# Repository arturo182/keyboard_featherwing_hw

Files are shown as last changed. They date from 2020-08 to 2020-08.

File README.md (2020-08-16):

# The Keyboard FeatherWing

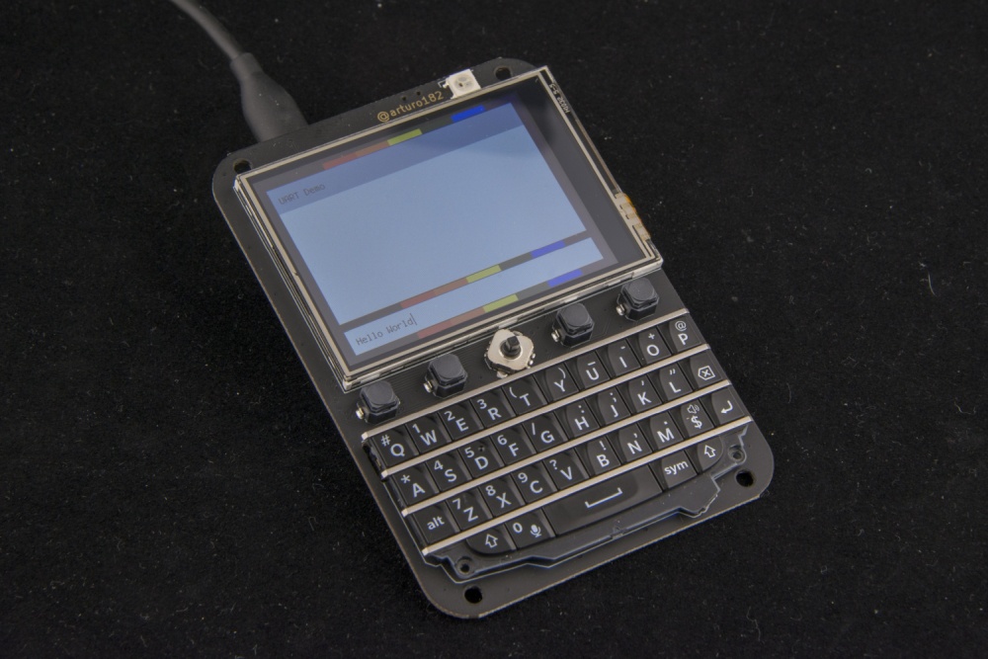
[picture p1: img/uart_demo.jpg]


The Keyboard FeatherWing is an easy way to add a handheld Qwerty keyboard and a 2.6” color display (+ more) to your project! It fits well in your hands and is great for typing with your thumbs, early 2000s-style.

The FeatherWing itself does not contain an MCU/CPU/SoC that you can program; you will need a board compatible with the [Adafruit Feather System](https://learn.adafruit.com/adafruit-feather/feather-specification).

# Technical details
- 2.6” 320x240 16-bit color LCD with resistive touch screen
- QWERTY keyboard
- 5-way button
- 4 soft tactile buttons
- A Neopixel
- microSD connector
- Stemma QT/Qwiic connector
- On/Off switch
- Dual row sockets
- Four mounting holes
- GPIO solder jumpers

# Links

For more information visit https://kfw.solder.party/

You can find example code here: https://github.com/arturo182/keyboard_featherwing_sw

This board uses a ATSAMD20 chip as a i2c peripheral that can be polled to get the key FIFO, the firmware for the SAM can be found here: https://github.com/arturo182/bbq10kbd_i2c_sw

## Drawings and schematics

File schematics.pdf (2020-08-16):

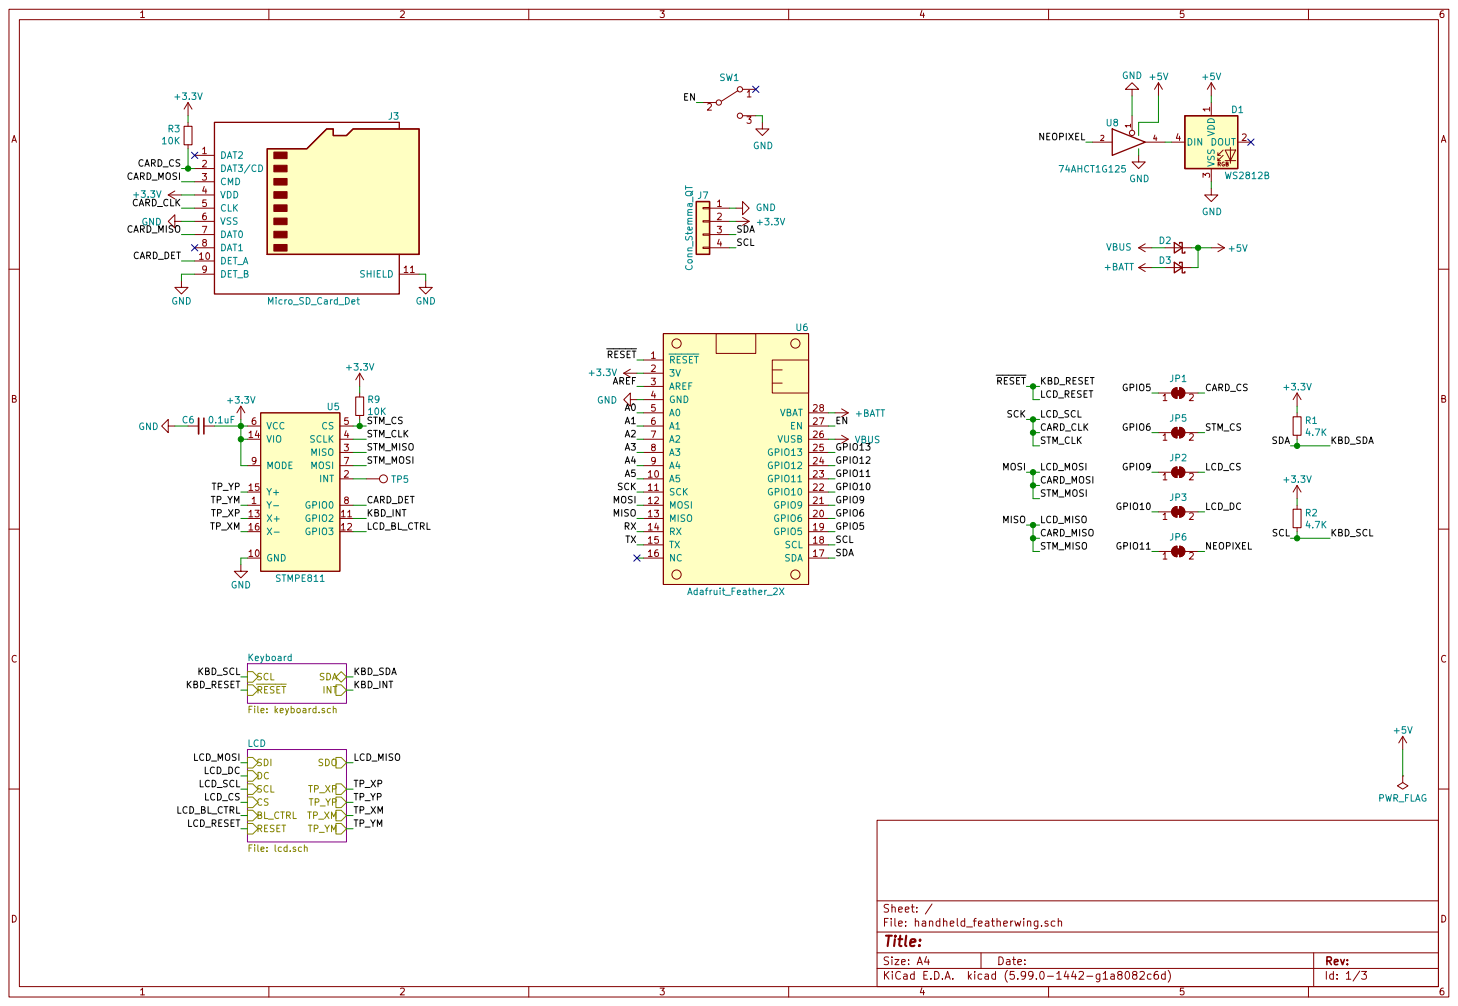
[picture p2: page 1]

File: handheld_featherwing.sch Sheet: / Keyboard

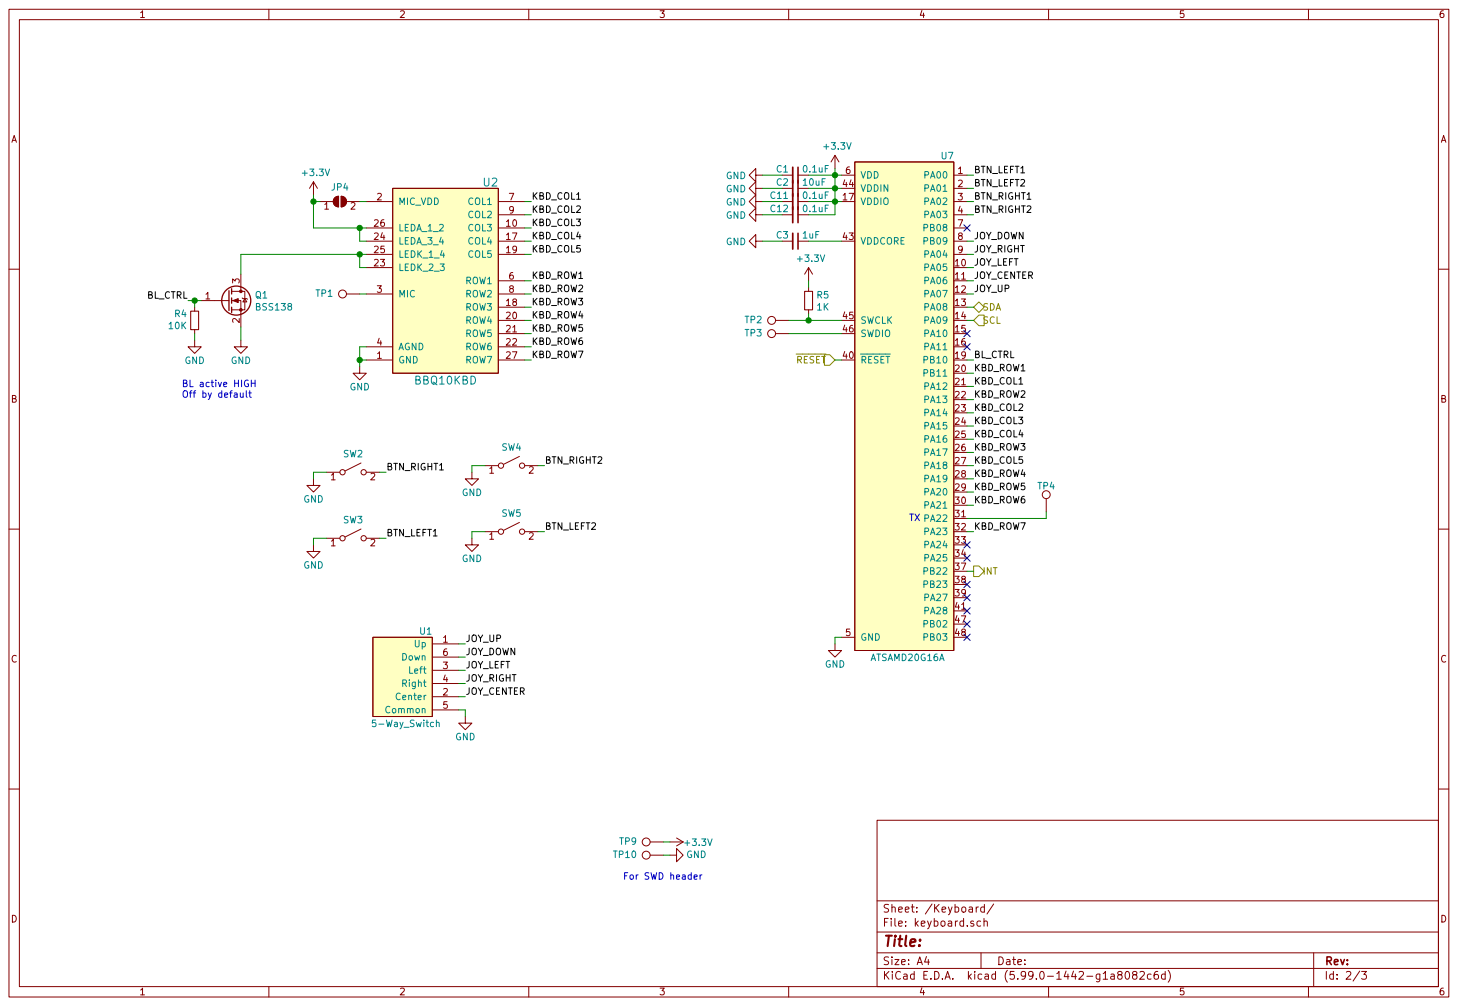
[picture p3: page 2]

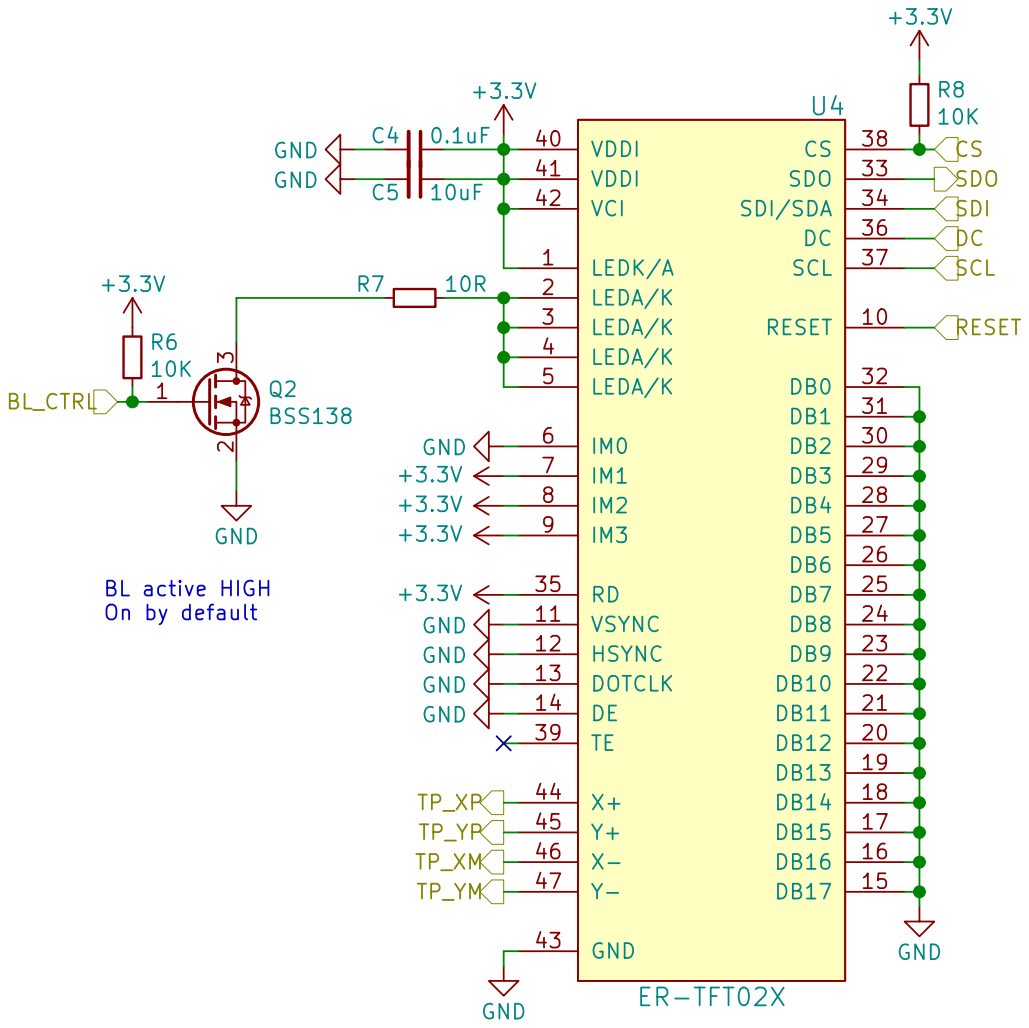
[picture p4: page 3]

Id: 3/3 Title: File: lcd.sch Sheet: /LCD/ GND GND

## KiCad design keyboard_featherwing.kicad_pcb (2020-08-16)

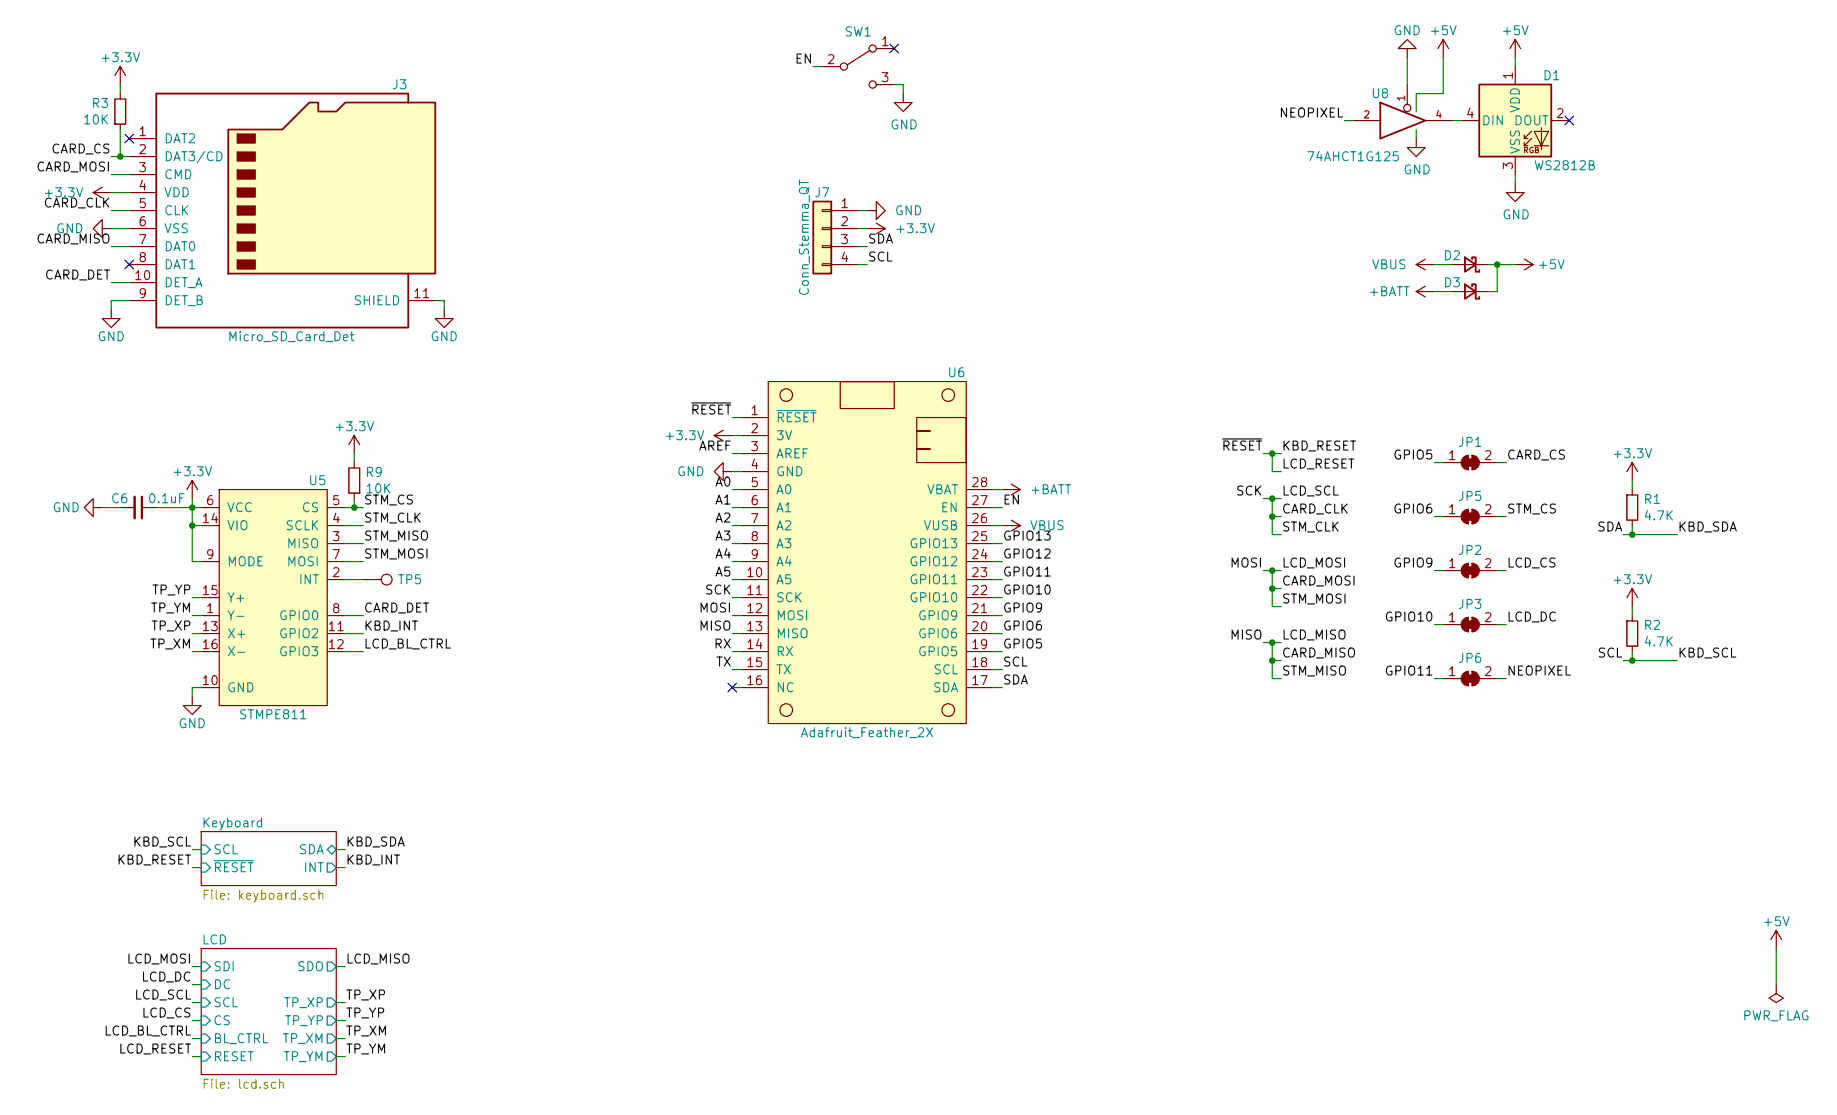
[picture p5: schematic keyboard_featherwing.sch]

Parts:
C6: 0.1uF; C_0603_1608Metric
D1: WS2812B; LED_WS2812B_PLCC4_5.0x5.0mm_P3.2mm
D2, D3: S1JHE; D_SOD-323_HandSoldering
J3: Micro_SD_Card_Det; microSD_HC_Molex_104031-0811
J7: Conn_Stemma_QT; JST_SH_SM04B-SRSS-TB_1x04-1MP_P1.00mm_Horizontal
JP1: SB_CARD_CS; SolderJumper-2_P1.3mm_Bridged_RoundedPad1.0x1.5mm
JP2: SB_LCD_CS; SolderJumper-2_P1.3mm_Bridged_RoundedPad1.0x1.5mm
JP3: SB_LCD_DC; SolderJumper-2_P1.3mm_Bridged_RoundedPad1.0x1.5mm
JP5: SB_STM_CS; SolderJumper-2_P1.3mm_Bridged_RoundedPad1.0x1.5mm
JP6: SB_NEOPIXEL; SolderJumper-2_P1.3mm_Bridged_RoundedPad1.0x1.5mm
R1, R2: 4.7K; R_0603_1608Metric
R3, R9: 10K; R_0603_1608Metric
SW1: SW_EN; SW_SPDT_PCM12
TP5: TP_STM_INT; TestPoint_Pad_D3.0mm
U5: STMPE811; QFN-16-1EP_3x3mm_P0.5mm_EP1.75x1.75mm
U6: Adafruit_Feather_2X; FeatherWing
U8: 74AHCT1G125; SOT-353_SC-70-5

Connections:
+3V3: C6.1, J3.4 (VDD), J7.2, R1.1, R2.1, R3.2, R9.2, U5.6 (VCC), U5.9 (MODE), U5.14 (VIO), U6.2 (3V); also elsewhere on the board
+5V: D1.1 (VDD), D2.1 (K), D3.1 (K), U8.5 (VCC)
+BATT: D3.2 (A), U6.28 (VBAT)
/A0: U6.5 (A0)
/A1: U6.6 (A1)
/A2: U6.7 (A2)
/A3: U6.8 (A3)
/A4: U6.9 (A4)
/A5: U6.10 (A5)
/AREF: U6.3 (AREF)
/CARD_CLK: J3.5 (CLK), U5.4 (SCLK), U6.11 (SCK); also elsewhere on the board
/CARD_CS: J3.2 (DAT3/CD), JP1.2 (B), R3.1
/CARD_DET: J3.10 (DET_A), U5.8 (GPIO0)
/CARD_MISO: J3.7 (DAT0), U5.3 (MISO), U6.13 (MISO); also elsewhere on the board
/CARD_MOSI: J3.3 (CMD), U5.7 (MOSI), U6.12 (MOSI); also elsewhere on the board
/EN: SW1.2 (B), U6.27 (EN)
/GPIO5: JP1.1 (A), U6.19 (GPIO5)
/GPIO6: JP5.1 (A), U6.20 (GPIO6)
/GPIO9: JP2.1 (A), U6.21 (GPIO9)
/GPIO10: JP3.1 (A), U6.22 (GPIO10)
/GPIO11: JP6.1 (A), U6.23 (GPIO11)
/GPIO12: U6.24 (GPIO12)
/GPIO13: U6.25 (GPIO13)
/KBD_INT: U5.11 (GPIO2); also elsewhere on the board
/KBD_RESET: U6.1 (~RESET~); also elsewhere on the board
/KBD_SCL: J7.4, R2.2, U6.18 (SCL); also elsewhere on the board
/KBD_SDA: J7.3, R1.2, U6.17 (SDA); also elsewhere on the board
/LCD_BL_CTRL: U5.12 (GPIO3); also elsewhere on the board
/LCD_CS: JP2.2 (B); also elsewhere on the board
/LCD_DC: JP3.2 (B); also elsewhere on the board
/NEOPIXEL: JP6.2 (B), U8.2
/RX: U6.14 (RX)
/STM_CS: JP5.2 (B), R9.1, U5.5 (CS)
/TP_XM: U5.16 (X-); also elsewhere on the board
/TP_XP: U5.13 (X+); also elsewhere on the board
/TP_YM: U5.1 (Y-); also elsewhere on the board
/TP_YP: U5.15 (Y+); also elsewhere on the board
/TX: U6.15 (TX)
GND: C6.2, D1.3 (VSS), J3.6 (VSS), J3.9 (DET_B), J3.11 (SHIELD), J7.1, SW1.3 (C), U5.10 (GND), U6.4 (GND), U8.1, U8.3 (GND); also elsewhere on the board
unnamed: D1.4 (DIN), U8.4
unnamed: TP5.1, U5.2 (INT)
VBUS: D2.2 (A), U6.26 (VUSB)

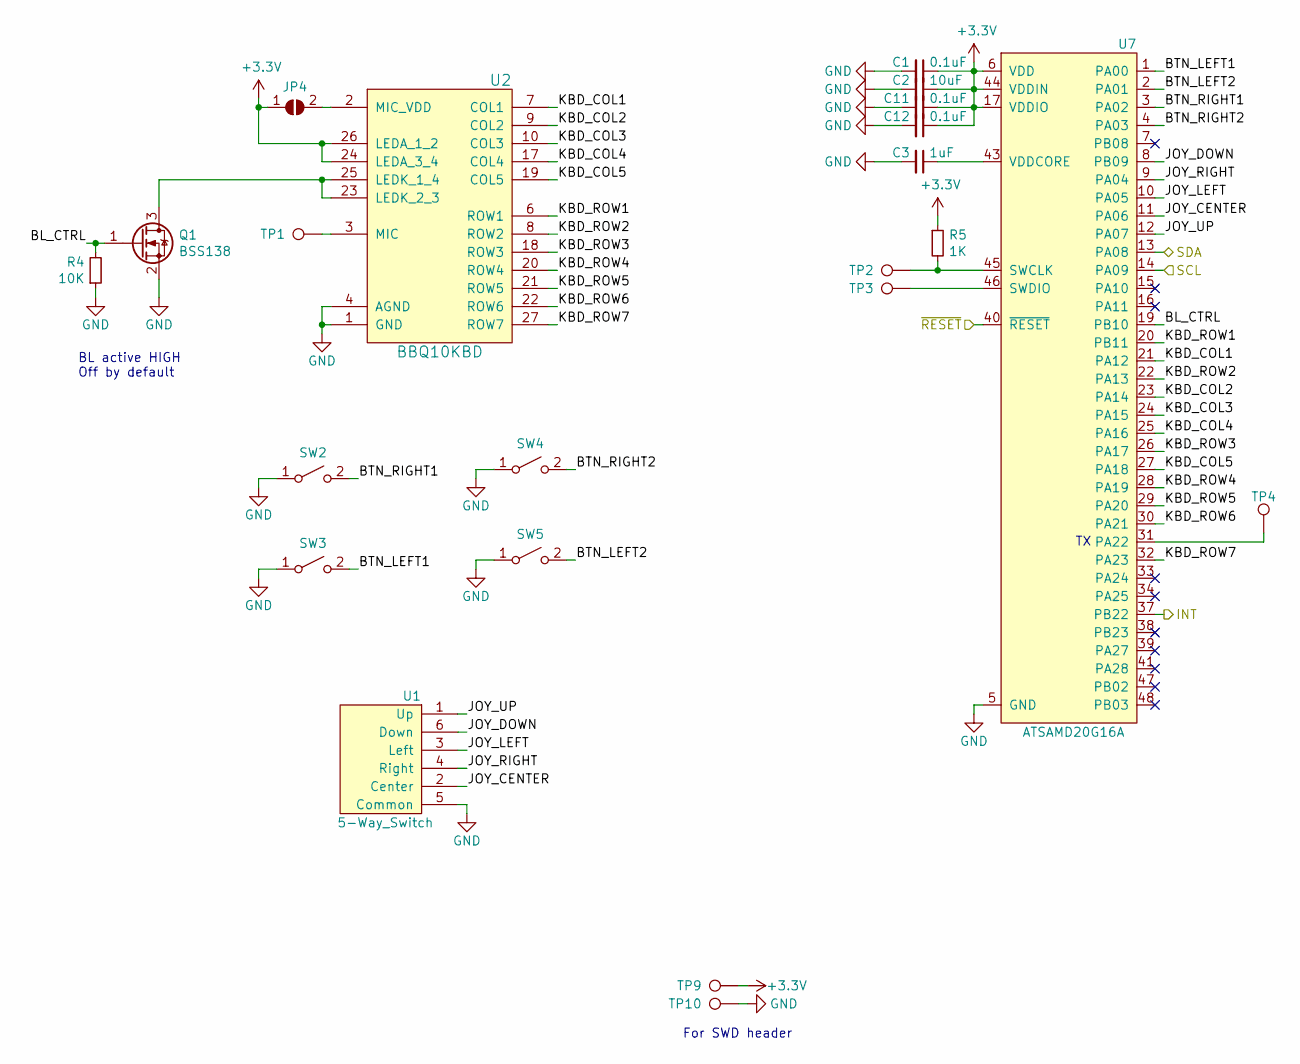
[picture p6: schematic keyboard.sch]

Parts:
C1, C11, C12: 0.1uF; C_0603_1608Metric
C2: 10uF; C_0603_1608Metric
C3: 1uF; C_0603_1608Metric
JP4: SB_MIC_VDD; SolderJumper-2_P1.3mm_Open_RoundedPad1.0x1.5mm
Q1: BSS138; SOT-23
R4: 10K; R_0603_1608Metric
R5: 1K; R_0603_1608Metric
SW2: SW_RIGHT1; RMT-CZ66
SW3: SW_LEFT1; RMT-CZ66
SW4: SW_RIGHT2; RMT-CZ66
SW5: SW_LEFT2; RMT-CZ66
TP1: TP_MIC; TestPoint_Pad_D3.0mm
TP2: TP_KBD_SWCLK; TestPoint_Pad_D3.0mm
TP3: TP_KBD_SWDIO; TestPoint_Pad_D3.0mm
TP4: TP_KBD_TX; TestPoint_Pad_D3.0mm
TP9: TP_KBD_3V; TestPoint_Pad_D3.0mm
TP10: TP_KBD_GND; TestPoint_Pad_D3.0mm
U1: 5-Way_Switch; SF303GJ26
U2: BBQ10KBD; BM14B(0.8)-24DS-0.4V(53)
U7: ATSAMD20G16A; QFN-48-1EP_7x7mm_P0.5mm_EP5.15x5.15mm

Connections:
+3V3: C1.1, C2.1, C11.1, C12.1, JP4.1 (A), R5.1, TP9.1, U2.24 (LEDA_3_4), U2.26 (LEDA_1_2), U7.6 (VDD), U7.17 (VDDIO), U7.36 (VDDIO), U7.44 (VDDIN); also elsewhere on the board
/KBD_INT: U7.37 (PB22); also elsewhere on the board
/KBD_RESET: U7.40 (~RESET~); also elsewhere on the board
/KBD_SCL: U7.14 (PA09); also elsewhere on the board
/KBD_SDA: U7.13 (PA08); also elsewhere on the board
/Keyboard/BL_CTRL: Q1.1 (G), R4.2, U7.19 (PB10)
/Keyboard/BTN_LEFT1: SW3.2 (B), U7.1 (PA00)
/Keyboard/BTN_LEFT2: SW5.2 (B), U7.2 (PA01)
/Keyboard/BTN_RIGHT1: SW2.2 (B), U7.3 (PA02)
/Keyboard/BTN_RIGHT2: SW4.2 (B), U7.4 (PA03)
/Keyboard/JOY_CENTER: U1.2 (Center), U7.11 (PA06)
/Keyboard/JOY_DOWN: U1.6 (Down), U7.8 (PB09)
/Keyboard/JOY_LEFT: U1.3 (Left), U7.10 (PA05)
/Keyboard/JOY_RIGHT: U1.4 (Right), U7.9 (PA04)
/Keyboard/JOY_UP: U1.1 (Up), U7.12 (PA07)
/Keyboard/KBD_COL1: U2.7 (COL1), U7.21 (PA12)
/Keyboard/KBD_COL2: U2.9 (COL2), U7.23 (PA14)
/Keyboard/KBD_COL3: U2.10 (COL3), U7.24 (PA15)
/Keyboard/KBD_COL4: U2.17 (COL4), U7.25 (PA16)
/Keyboard/KBD_COL5: U2.19 (COL5), U7.27 (PA18)
/Keyboard/KBD_ROW1: U2.6 (ROW1), U7.20 (PB11)
/Keyboard/KBD_ROW2: U2.8 (ROW2), U7.22 (PA13)
/Keyboard/KBD_ROW3: U2.18 (ROW3), U7.26 (PA17)
/Keyboard/KBD_ROW4: U2.20 (ROW4), U7.28 (PA19)
/Keyboard/KBD_ROW5: U2.21 (ROW5), U7.29 (PA20)
/Keyboard/KBD_ROW6: U2.22 (ROW6), U7.30 (PA21)
/Keyboard/KBD_ROW7: U2.27 (ROW7), U7.32 (PA23)
GND: C1.2, C2.2, C3.2, C11.2, C12.2, Q1.2 (S), R4.1, SW2.1 (A), SW3.1 (A), SW4.1 (A), SW5.1 (A), TP10.1, U1.5 (Common), U1.SHIELD, U2.1 (GND), U2.4 (AGND), U2.5 (GND), U2.11 (GND), U2.12 (GND), U2.13 (GND), U2.14 (GND), U2.15 (GND), U2.16 (GND), U2.28 (GND), U7.5 (GND), U7.18 (GND), U7.35 (GND), U7.42 (GND); also elsewhere on the board
unnamed: C3.1, U7.43 (VDDCORE)
unnamed: JP4.2 (B), U2.2 (MIC_VDD)
unnamed: Q1.3 (D), U2.23 (LEDK_2_3), U2.25 (LEDK_1_4)
unnamed: R5.2, TP2.1, U7.45 (SWCLK)
unnamed: TP1.1, U2.3 (MIC)
unnamed: TP3.1, U7.46 (SWDIO)
unnamed: TP4.1, U7.31 (PA22)

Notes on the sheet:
BL active HIGH Off by default
For SWD header

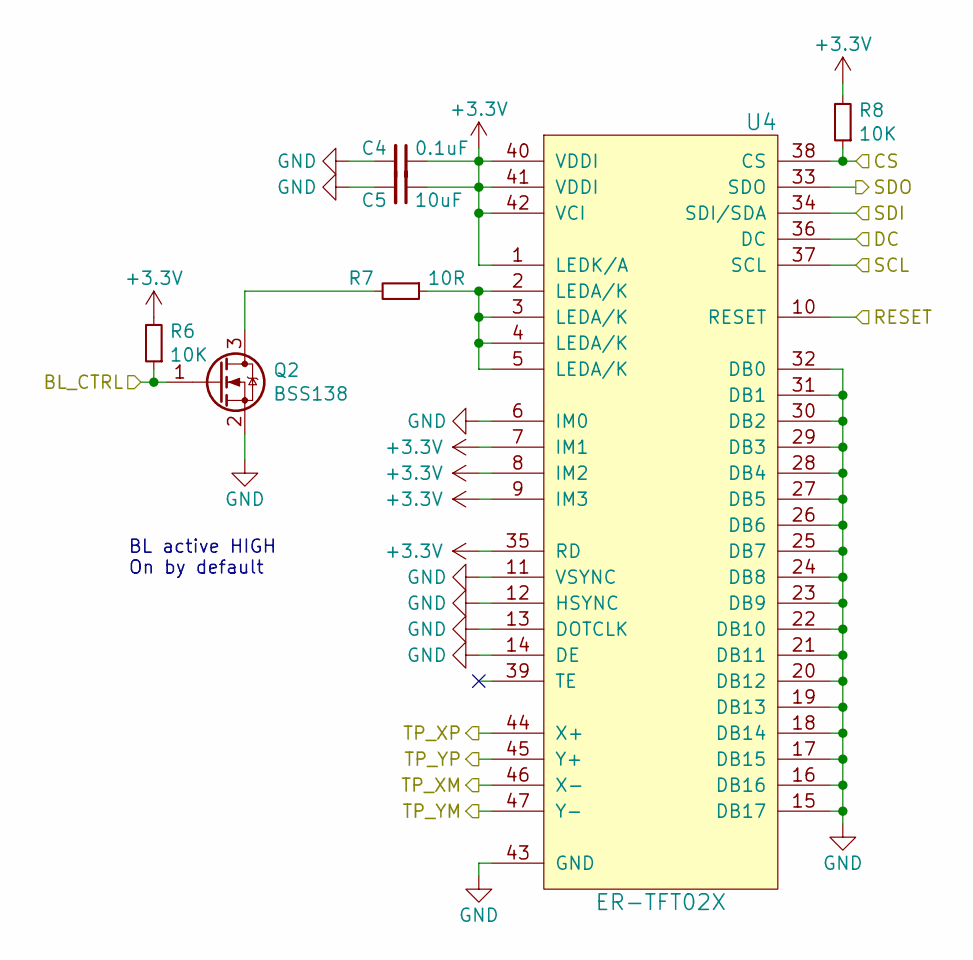
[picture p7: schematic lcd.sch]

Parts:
C4: 0.1uF; C_0603_1608Metric
C5: 10uF; C_0603_1608Metric
Q2: BSS138; SOT-23
R6, R8: 10K; R_0603_1608Metric
R7: 10R; R_0603_1608Metric
U4: ER-TFT02X; ER-CON50HT-1

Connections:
+3V3: C4.1, C5.1, R6.2, R8.2, U4.1 (LEDK/A), U4.7 (IM1), U4.8 (IM2), U4.9 (IM3), U4.35 (RD), U4.40 (VDDI), U4.41 (VDDI), U4.42 (VCI); also elsewhere on the board
/CARD_CLK: U4.37 (SCL); also elsewhere on the board
/CARD_MISO: U4.33 (SDO); also elsewhere on the board
/CARD_MOSI: U4.34 (SDI/SDA); also elsewhere on the board
/KBD_RESET: U4.10 (RESET); also elsewhere on the board
/LCD_BL_CTRL: Q2.1 (G), R6.1; also elsewhere on the board
/LCD_CS: R8.1, U4.38 (CS); also elsewhere on the board
/LCD_DC: U4.36 (DC); also elsewhere on the board
/TP_XM: U4.46 (X-); also elsewhere on the board
/TP_XP: U4.44 (X+); also elsewhere on the board
/TP_YM: U4.47 (Y-); also elsewhere on the board
/TP_YP: U4.45 (Y+); also elsewhere on the board
GND: C4.2, C5.2, Q2.2 (S), U4.6 (IM0), U4.11 (VSYNC), U4.12 (HSYNC), U4.13 (DOTCLK), U4.14 (DE), U4.15 (DB17), U4.16 (DB16), U4.17 (DB15), U4.18 (DB14), U4.19 (DB13), U4.20 (DB12), U4.21 (DB11), U4.22 (DB10), U4.23 (DB9), U4.24 (DB8), U4.25 (DB7), U4.26 (DB6), U4.27 (DB5), U4.28 (DB4), U4.29 (DB3), U4.30 (DB2), U4.31 (DB1), U4.32 (DB0), U4.43 (GND), U4.48 (GND), U4.49 (GND), U4.50 (GND); also elsewhere on the board
unnamed: Q2.3 (D), R7.2
unnamed: R7.1, U4.2 (LEDA/K), U4.3 (LEDA/K), U4.4 (LEDA/K), U4.5 (LEDA/K)

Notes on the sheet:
BL active HIGH On by default

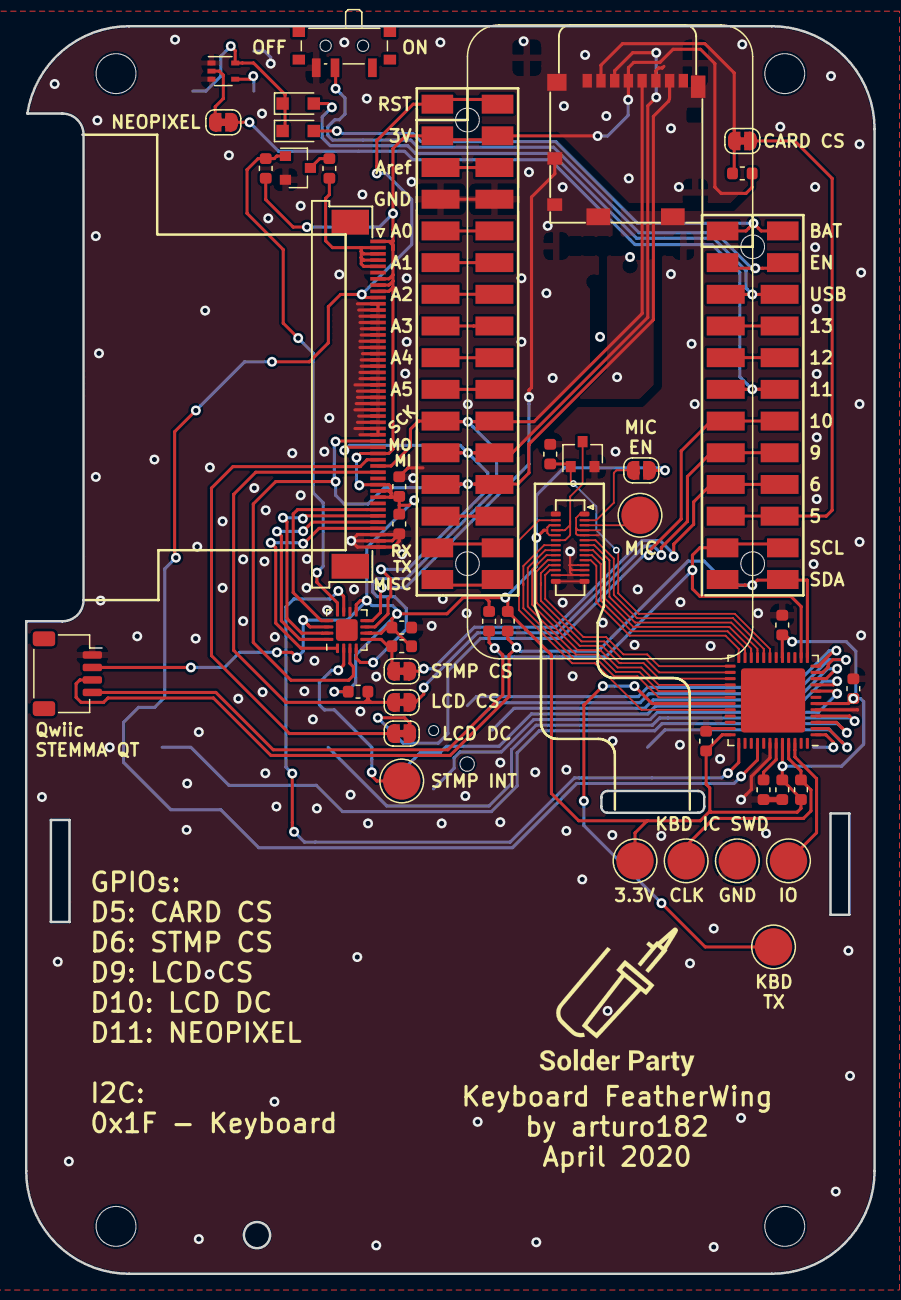
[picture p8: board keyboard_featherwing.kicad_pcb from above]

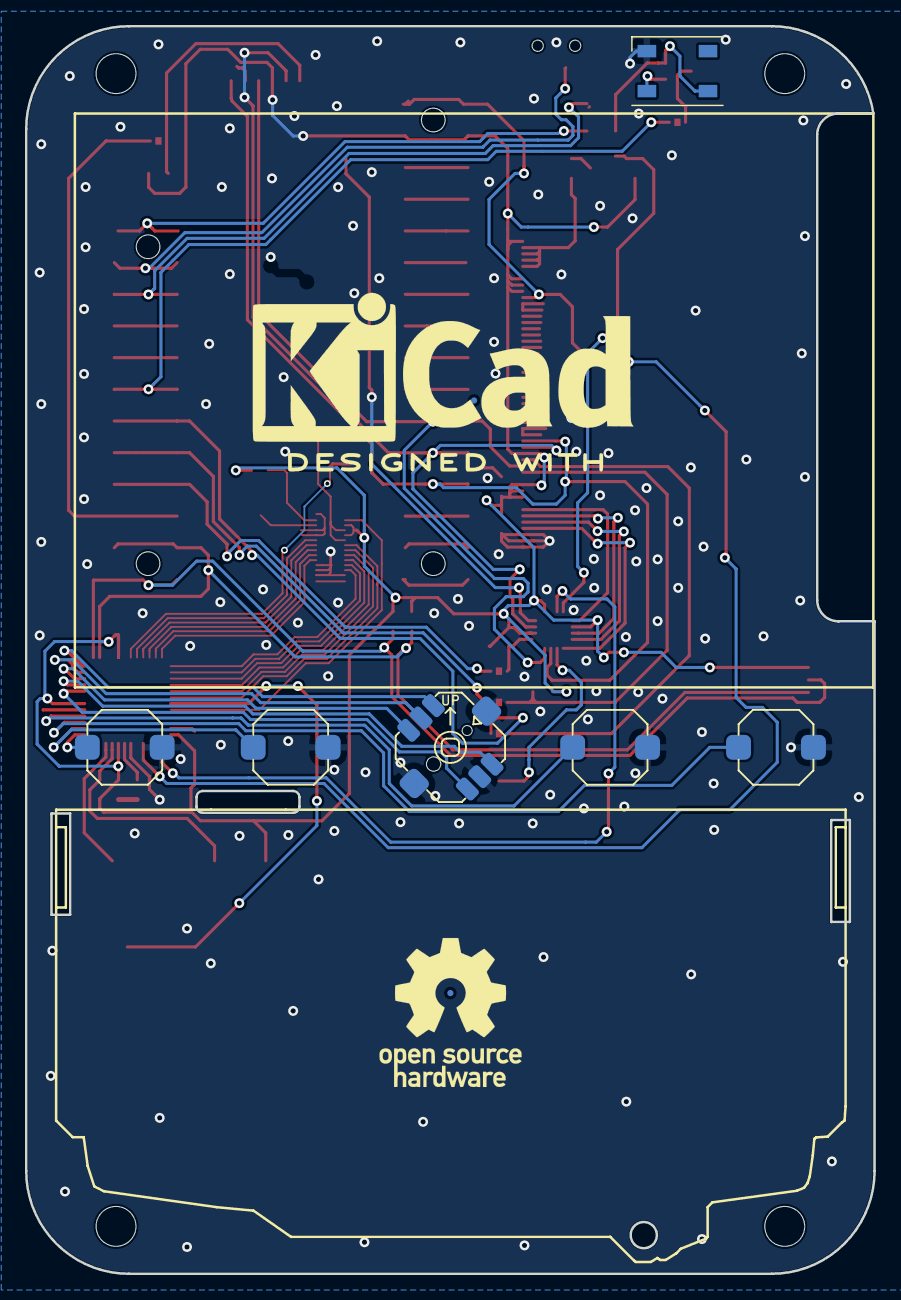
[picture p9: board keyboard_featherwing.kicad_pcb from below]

Board: 2 copper layers, 68.0 x 100.0 mm, 49 parts (6 on the bottom side), 62 nets.

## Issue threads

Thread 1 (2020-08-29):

Zone fills are out-of-date

rampageservices, 2020-08-29:
Hello!

I took a look at your design in KiCad with v5.99.
It looked a bit strange and I realized that the zone fills are out-of-date on the checked in PCB design file.
Running the DRC fixes this.
I didn't create a PR because it's probably best that you do it on your end to prevent differences from the production version.
Just thought I'd give you a heads up.

Great design by the way!

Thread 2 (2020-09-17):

SD Card Detect does not work

btashton, 2020-09-17:
There is no pull-up resistor on the DET_A line so the line goes between floating and GND.  The STMPE811 unfortunately cannot be configured to offer the pull-up.  I  was able to rework my board a bit to sneak a 10k resistor in, but I would caution anyone that does this to remove the cover of the SD slot before wiring or the solder will likely wick up the switch and short it out to the case.

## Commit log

2019-05-08 Initial import
    [handheld_featherwing.kicad_pcb, handheld_featherwing.sch, keyboard.sch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]
2019-06-15 Finish up rev1
    [handheld_featherwing.kicad_pcb, handheld_featherwing.sch, keyboard.sch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]
2020-03-24 Rev 3
    [handheld_featherwing.kicad_pcb, handheld_featherwing.sch, keyboard.sch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]
2020-04-09 Rev 4!
    [bom.xls, handheld_featherwing.kicad_pcb, handheld_featherwing.sch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]
2020-08-16 Rename handheld->keyboard
    [keyboard_featherwing.kicad_pcb, keyboard_featherwing.sch]
2020-08-16 Rev5, production
    [keyboard_featherwing.kicad_pcb, keyboard_featherwing.sch]
